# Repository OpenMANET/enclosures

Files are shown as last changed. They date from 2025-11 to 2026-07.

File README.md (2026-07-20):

# OpenMANET Enclosures

This repository collects 3D-printable and off-the-shelf enclosure designs that support OpenMANET nodes and accessories.

## Available Enclosures

| Name | Description |
|---|---|
| [Get Started Enclosure](GetStarted/README.md) | Simple Snap-fit Raspberry Pi 4 + HaLow enclosure with multiple UPS/no-UPS variants and ABS/ASA print guidance. |
| [OpenNot5](OpenNot5/README.md) | Aluminum or 3D printed field chassis that integrates a Pi 4B, Waveshare 3S UPS, and waterproof bulkhead connectors. MakerWorld listing: https://makerworld.com/en/models/2128181-openmanet-radio-case |
| [OpenChubNET](OpenChubNET/README.md) | 3D printed, Pi4B, Waveshare UPS D, CAZN connectors. Option for DIY top lids |
| [Hammond Enclosure](Hammond/README.md) | OpenMANET enclosure for a Pi 4B using a Hammond 1457K1201BK case plus printed cap/carrier tray; optional inline connector simplifies switch-to-PiSugar wiring for easier rework. |
| [PRC-148 / PRC-152 Battery](PRC-148-152-Battery/README.md) | Early community design for a 3S2P 18650 twist-lock radio battery and matching radio-side mount. |
| [Sunkworks VLM-PT1 Enclosure](<Sunkworks VLM PT1 Enclosure/README.md>) | Compact two-piece enclosure for the OpenVLM VLM-KW USB voice/PTT interface, with print files, hardware requirements, and assembly notes. |

## Other Prints

| Name | Description |
|---|---|
| [GIZOisNT](GIZOisNT_Antenna/README.md) | Tactical Gooseneck Antenna |

## Photo Gallery

**Get Started**

Get Started no-UPS build

**OpenNot5**

OpenNot5 field build

**OpenChubNET**

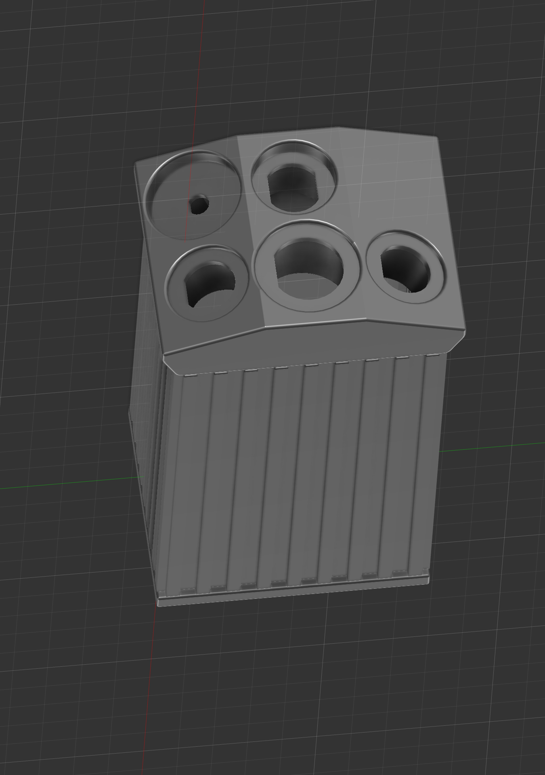
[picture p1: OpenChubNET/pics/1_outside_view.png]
OpenChubNET render


**Hammond**

Hammond enclosure front angle

Hammond enclosure rear angle

Hammond enclosure open with PiSugar 3 Plus

**Sunkworks VLM-PT1**

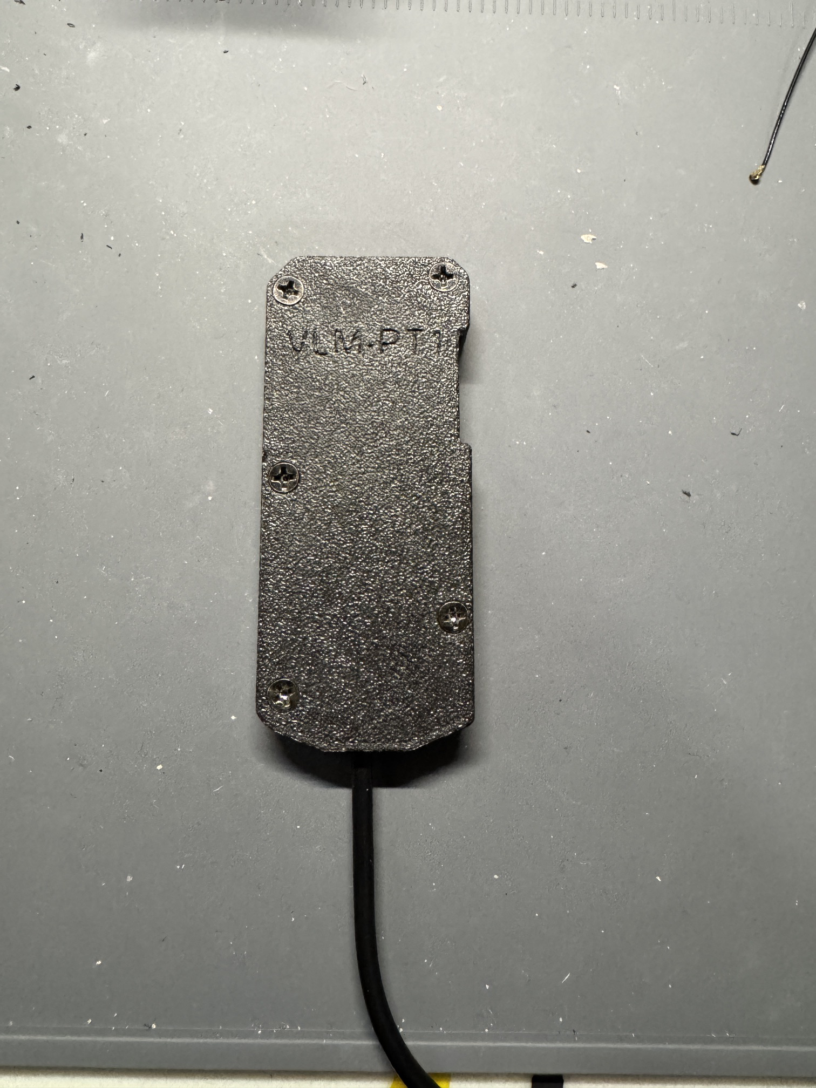
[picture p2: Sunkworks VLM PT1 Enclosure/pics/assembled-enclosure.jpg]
Assembled Sunkworks VLM-PT1 enclosure


**GIZOisNT**

GIZOisNT

## Contributing

1. Create a directory named after your enclosure.
2. Add a `README.md` describing the use case, assembly steps, and parts list (note optional vs required parts).
3. Include any supporting assets (STL files, wiring diagrams, photos) inside the same directory.

PRs that follow the structure above make it easier for others to build repeatable OpenMANET hardware.

## License

All content in this repository is provided under the [Creative Commons Attribution-NonCommercial 4.0 International](LICENSE) license. Commercial use requires explicit permission from the creator.

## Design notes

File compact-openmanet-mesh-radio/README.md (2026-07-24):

# Compact OpenMANET Mesh Radio Build

## Overview

This project is a compact radio-style mesh build designed around a 3D printed enclosure and internally mounted electronics. The enclosure is intended to keep the build clean, compact and practical, with externally mounted antennas and room for the required power and radio components.

Several versions and layout options are included in the full project repository. These include different enclosure versions, component layouts, antenna mounting options and internal build approaches.

Full repository:
https://github.com/ties1887/Mesh-radio-Halow-LoRa

## Preview pictures

<p align="center">
  
  
</p>

<p align="center">
  
  
</p>

<p align="center">
  db9d3973-dfbc-4dac-b72b-2cc7cdb6f751
  
</p>

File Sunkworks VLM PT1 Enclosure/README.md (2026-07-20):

# Sunkworks VLM-PT1 Enclosure

Compact two-piece enclosure for the OpenVLM VLM-KW USB voice/PTT interface.

Assembled VLM-PT1 enclosure

## Overview

- Fits the [Builds By Shane VLM-KW board](https://www.buildsbyshane.com/shop/p/product-3-szb2y-gzh2r-tzhkx-xahl8).
- Uses five heat-set inserts and five flat-head screws.
- Routes the USB and Kenwood-style PTT cables through opposite ends of the case.
- The included STL contains both enclosure halves.

A ready-made [Sunkworks VLM-PT1 enclosure kit](https://sunkworkstec.com/products/sw-vlm-pt1)
is printed in PPA-CF and includes mounting hardware and one selected USB cable.
The VLM board and PTT are sold separately.

## Photos

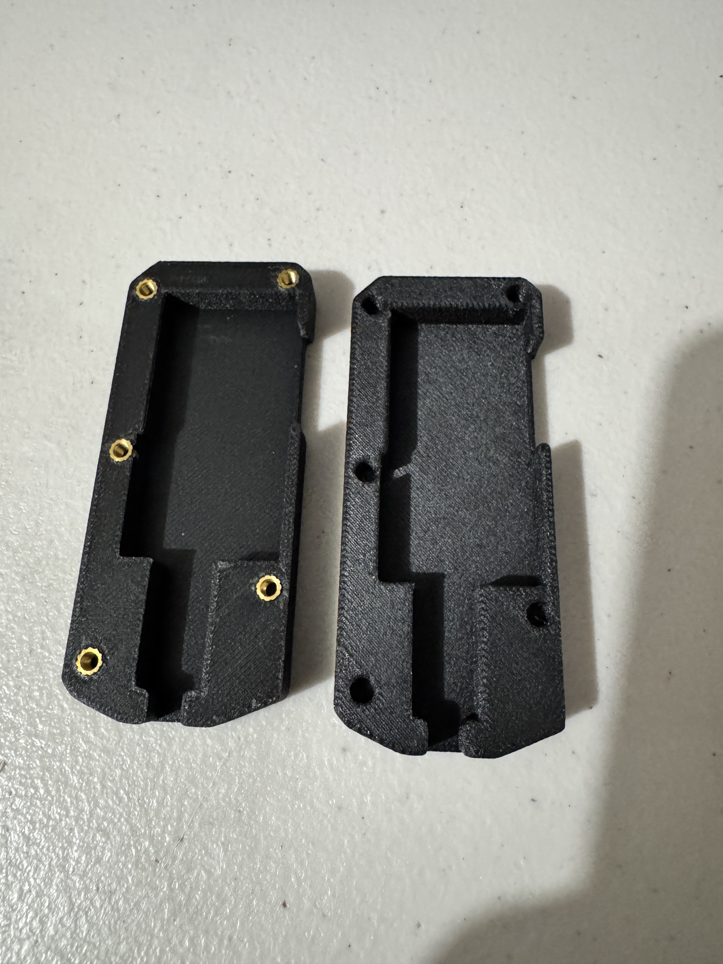
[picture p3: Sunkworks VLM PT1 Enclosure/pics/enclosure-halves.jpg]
Inside faces of the two printed VLM-PT1 enclosure halves


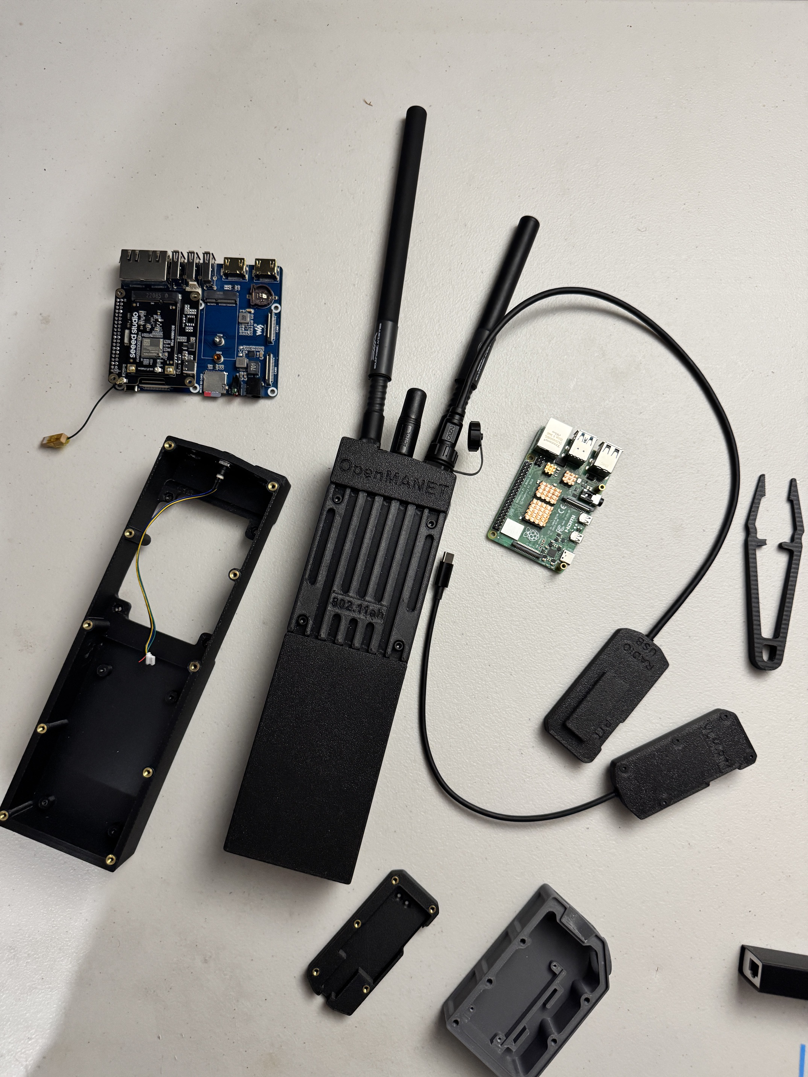
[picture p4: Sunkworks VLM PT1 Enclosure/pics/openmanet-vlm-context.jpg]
VLM-PT1 enclosure shown with OpenMANET hardware


## Bill of Materials

| Qty | Item | Notes |
|-----|---|---|
| 1 | VLM-KW board | Purchased separately |
| 1 | Printed VLM-PT1 enclosure | Both halves are in the included STL |
| 5 | M3 x 3 mm heat-set inserts | Install in the enclosure bosses |
| 5 | M3 x 6 mm flat-head Phillips screws | Join the enclosure halves |
| 1 | USB host cable | Match the connector to the host device |
| 1 | Compatible Kenwood 2-pin PTT | Purchased separately |

## Printing

1. Import [`stl/vlm-pt1-enclosure.stl`](stl/vlm-pt1-enclosure.stl).
2. Split the model into its two shell components.
3. Move the shells apart and orient each one separately for printing.
4. Confirm that the heat-insert bosses print cleanly before assembly.

## Assembly

1. Print and clean both enclosure halves.
2. Install the five M3 x 3 mm heat-set inserts, keeping them square and flush.
3. Dry-fit the VLM-KW board and route the USB and PTT cables through the case
   openings without pinching them.
4. Join the shells with the five M3 x 6 mm screws and tighten only until the seam
   closes.
5. Test the VLM before field use.

## Source Files

- [`stl/vlm-pt1-enclosure.stl`](stl/vlm-pt1-enclosure.stl) — both enclosure halves
- [`hardware/parts.txt`](hardware/parts.txt) — original fastener and cable notes
- [`pics/`](pics) — assembly and context photos

## Related Links

- [Sunkworks VLM-PT1 enclosure kit](https://sunkworkstec.com/products/sw-vlm-pt1)
- [OpenMANET/OpenVLM repository](https://github.com/OpenMANET/OpenVLM)
- [Builds By Shane VLM-KW board](https://www.buildsbyshane.com/shop/p/product-3-szb2y-gzh2r-tzhkx-xahl8)

## License

Repository content is covered by the root
[CC BY-NC 4.0 license](../LICENSE). The OpenVLM board and software repositories
carry their own licenses; review those projects before redistributing their
files.

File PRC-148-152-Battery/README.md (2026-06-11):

# PRC-148 / PRC-152 Battery

DIY rechargeable battery enclosure and radio-side mounting interface for
PRC-148 / PRC-152-style OpenMANET radios. The battery uses six 18650 cells in a
3S2P configuration and copies the nominal voltage and twist-lock interface of a
PRC-148 battery.

This is an early community design by Mark. The recovered source files and known
build details are collected here so the design can be tested, documented, and
improved.

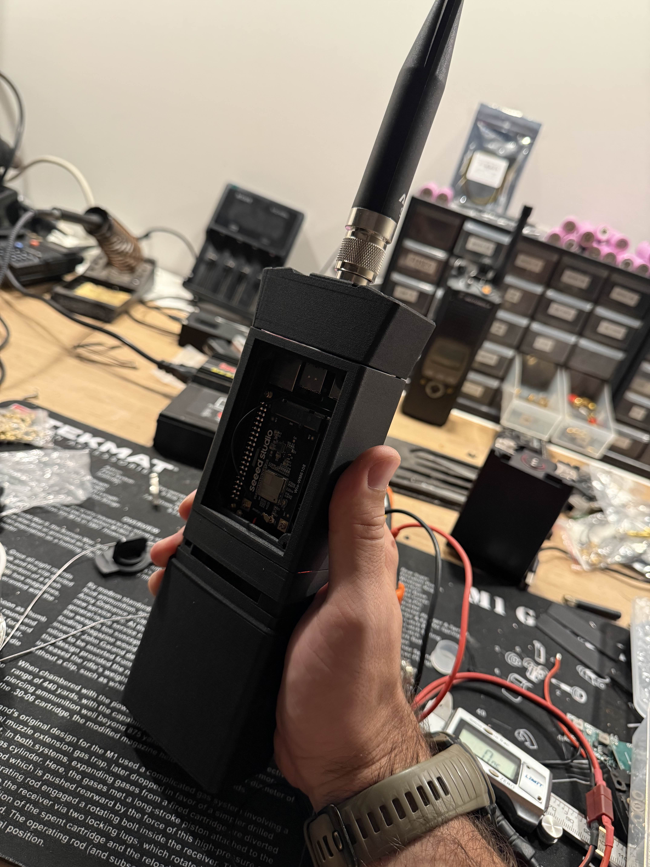
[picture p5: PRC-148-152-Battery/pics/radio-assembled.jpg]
Assembled radio and battery


> [!CAUTION]
> Building lithium-ion packs can cause fire, serious injury, or property damage.
> Use matched, genuine cells; a suitable 3S BMS; insulated weldable battery
> tabs; a current-limited spot welder; and a charger specifically intended for a
> 3S lithium-ion pack. Verify polarity, isolation, and pack voltage before
> connecting the battery to a radio.

## Status

The original prototype has been built and operated, but this is not yet a
complete, independently verified build guide. See [Open Questions](#open-questions)
before ordering parts or assembling a pack.

The interface is intended to accept genuine-style PRC-148 batteries as well.
Mark reported that an original battery physically fitted, but genuine-battery
electrical compatibility has not been independently verified.

The optional interface PCBs are also prototype hardware. In the June 2026
discussion, board revision `0.1` had been ordered but had not yet been reported
as electrically validated. Review the KiCad source and verify every net before
connecting a battery or radio.

## Electrical Specification

| Item | Specification |
|---|---|
| Cell type | 6 x 18650 lithium-ion cells |
| Cell configuration | 3S2P |
| Nominal pack voltage | 10.8 V |
| Maximum pack voltage | 12.6 V |
| Prototype cell capacity | Approximately 3400-3500 mAh per cell |
| Approximate pack capacity | 6800-7000 mAh, depending on cells |
| Protection / balancing | 3S BMS |
| Charging | Standard 12.6 V 3S lithium-ion charger through the top connector |
| Positive contacts | Two outer circular contacts |
| Data contact | Middle circular contact; routed through the optional interface PCBs but unused by the basic battery |
| Ground contacts | Both stainless-steel twist-lock tabs, connected to protected BMS output negative |
| Positive contact rating | Mark reports 2-3 A at 12 V per pin; two positive pins are used in parallel |

The BMS balance connections must be connected at the 4.2 V and 8.4 V series
nodes. Each node joins the corresponding parallel cell pair. Do not treat these
as optional outputs.

Mark's prototype was charged using an inexpensive generic 12.6 V 3S
lithium-ion charger. A charging dock can use the same mechanical interface as
the radio-side mount. A commercial `SN-832-KIT Rev B` charging-adapter STEP file
was shared in Discord as a mechanical reference, but it is not included here
because its redistribution license is unknown.

The interface PCBs do not convert the pack voltage. The radio still requires a
separate regulator or power supply suitable for its electronics. An MP1584EN
module was used elsewhere in Mark's prototype, but Mark described it as
temporary and community discussion identified RF-emission concerns.

## Mechanical Interface

The two stainless-steel tabs are both structural twist-lock features and
electrical ground contacts. Their angled surfaces tighten the battery against
the radio as the battery rotates into place. They must be conductive and cannot
be replaced with plastic prints.

Mark's prototype used SLM-printed 316L stainless-steel tabs. He reported a cost
of about USD $10 per pair. His PCBWay reference settings for the older
`Falcon Battery Tab v8` were:

| Item | Setting |
|---|---|
| Dimensions | 40.44 x 39.60 x 3.00 mm |
| Material | Stainless steel 316L |
| Process | SLM |
| Threads / inserts | None |

Mark subsequently modified the tab to fit countersunk pieces, so do not treat
the `v8` dimensions as the final production model. Sheet metal may also work if
it can be formed accurately, but that approach has not been documented or
verified here.

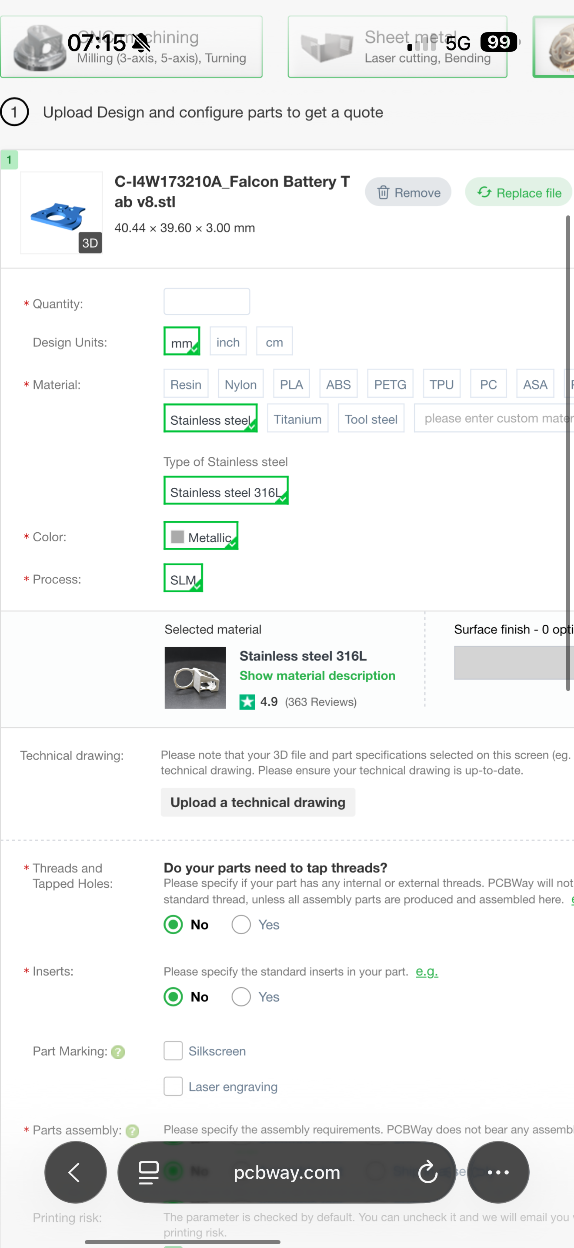
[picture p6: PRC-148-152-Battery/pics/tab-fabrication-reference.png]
PCBWay settings for the older Falcon Battery Tab v8


The center contact arrangement is:

| Side | Contact |
|---|---|
| Radio | 6 mm spring-loaded pogo pins |
| Battery | 2.0 x 7.0 mm flat-top pins, 1.5 mm body, no spring |

The pins are pushed in from the top with a tight friction fit. The prototype's
printed holes required minor drilling. Solder quickly to avoid heat damage;
wire-wrapping the pin before soldering is recommended.

An O-ring seals the circular contact insert. Mark specified `13.9 x 1.8 mm`.

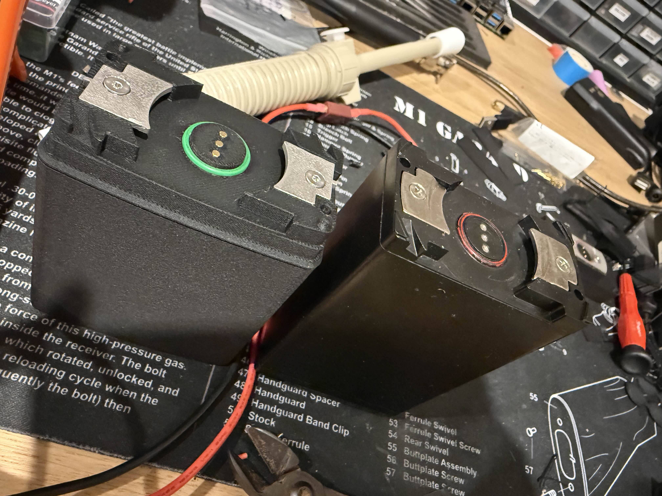
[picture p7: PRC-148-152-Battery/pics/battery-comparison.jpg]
Battery and commercial reference battery


## Related Electronics

The companion [mattronix/battery-board](https://github.com/mattronix/battery-board)
project replaces point-to-point wiring at the mechanical interface with two
PCBs.

### Battery-Side PCB

The battery board connects the BMS/output harness to the contacts and adds one
resettable fuse before the two parallel positive contacts.

| JST XH 3-pin | Signal | Destination |
|---|---|---|
| Pin 1 | `GND` | Both conductive twist-lock tabs |
| Pin 2 | `DATA` | Middle flat contact |
| Pin 3 | Raw `VBAT+` | Resettable fuse, then both outer positive contacts |

Connect the BMS protected output positive and negative to this harness. The
board's fuse protects the positive contacts, but it does not replace the 3S BMS.

### Radio-Side PCB

The radio board combines the two positive pogo pins, passes them through an
always-on P-channel MOSFET reverse-polarity stage, then through a 5 mOhm shunt.
An INA226 measures bus voltage and current across that shunt. The board does not
regulate the battery voltage.

| JST XH 6-pin | Signal | Purpose |
|---|---|---|
| Pin 1 | `GND` | Ground / both conductive twist-lock tabs |
| Pin 2 | `DATA` | Direct pass-through from the middle battery contact |
| Pin 3 | `SDA` | INA226 I2C data |
| Pin 4 | `SCL` | INA226 I2C clock |
| Pin 5 | `3V3` | Host-supplied INA226 power |
| Pin 6 | `VBAT+` | Monitored/protected battery output |

The middle `DATA` contact is independent of the INA226. INA226 telemetry uses
the separate `SDA` and `SCL` harness pins and requires host software. The
current design grounds both INA226 address pins and leaves its alert output
unconnected.

The PCB project is licensed separately under CERN-OHL-W-2.0.

> [!WARNING]
> The board repository's prose documentation has described the INA226 as
> reporting over the battery `DATA` line. The current KiCad design does not do
> that: `DATA` is a separate pass-through, while the INA226 uses `SDA` and `SCL`
> on the radio-side six-pin harness.

## Bill of Materials

| Qty | Part | Known specification / source | Notes |
|-----|---|---|---|
| 6 | 18650 cells | Matched 3.6 V nominal cells | Prototype used 3400-3500 mAh cells |
| 1 | 3S BMS | [Original AliExpress listing](https://www.aliexpress.com/item/1005009778488275.html) | Confirm current rating and wiring before assembly |
| 3 | Radio-side spring contacts | [6 mm pogo pin listing](https://www.aliexpress.com/item/1005006095992803.html) | Used on radio side |
| 3 | Battery-side flat contacts | [Original listing](https://www.aliexpress.com/item/32862727404.html) | 2.0 x 7.0 mm, 1.5 mm body, no spring |
| 1 | O-ring | 13.9 x 1.8 mm | Circular contact insert seal |
| 2 | Conductive twist-lock tabs | SLM-printed 316L stainless steel | Both tabs are ground contacts |
| 1 set | Cell interconnects | Weldable battery tabs sized for expected current | Mark welded tabs to the cells, then soldered cables to the tabs; confirm tab material |
| 1 set | Wire and insulation | Sized for expected current and pack voltage | Include fish paper / equivalent cell insulation |
| 1 | 3S lithium-ion charger | 12.6 V CC/CV charger | Connects through top interface |
| 1 set | Fasteners / inserts | To be confirmed | See Open Questions |
| Optional | Battery and radio interface PCBs | [mattronix/battery-board](https://github.com/mattronix/battery-board) | Adds contact breakout, battery-side resettable fuse, radio-side reverse-polarity protection, and INA226 monitoring |

## Source Files

### Battery

The [`cad/battery`](cad/battery) directory contains:

- `Battery Case` Fusion 360 and STL files
- `BatteryTop v1` Fusion 360 and STL files
- `18650 Holder Top` Fusion 360 and STL files
- `18650 Holder Bottom` Fusion 360 and STL files
- `Falcon Battery Tab v13` conductive twist-lock tab Fusion 360 and STL files
- `PRC Cell.3mf` prepared multi-part print project

### Radio

The [`cad/radio`](cad/radio) directory contains the matching
`148_152_Radio_Bottom` Fusion 360 and STL files.

`Falcon Battery Tab v13` is the current available conductive-tab design and
includes both an editable Fusion 360 source and an STL.

## Assembly Outline

1. Print and dry-fit all battery parts and the radio-bottom counterpart.
2. Obtain or manufacture the conductive stainless-steel twist-lock tabs.
3. Install the flat battery-side contacts and O-ring in the battery top.
4. Build a matched 3S2P cell pack using a spot welder and suitable insulation.
   Mark spot-welded tabs to the cells and then soldered cables to the tabs. Do
   not solder directly to bare cells.
5. Wire both parallel groups to the BMS, including the 4.2 V and 8.4 V balance
   nodes.
6. If wiring without the battery-side PCB, connect both outer circular contacts
   to BMS protected output positive and leave the middle data contact unused.
   If using the PCB, connect BMS protected output positive to JST pin 3; the
   board's resettable fuse feeds both positive contacts.
7. Connect both conductive twist-lock tabs to BMS protected output negative,
   not directly to raw cell negative. With the battery-side PCB, use JST pin 1.
8. Leave battery-board JST pin 2 / the middle `DATA` contact disconnected unless
   implementing a compatible battery-side data system. It is not used for
   INA226 monitoring.
9. Verify there are no shorts between positive, data, ground tabs, or exposed
   fasteners.
10. Confirm correct polarity and pack voltage with a multimeter before mating
    the battery to the radio.
11. Perform initial charge and load testing in a fire-resistant location.

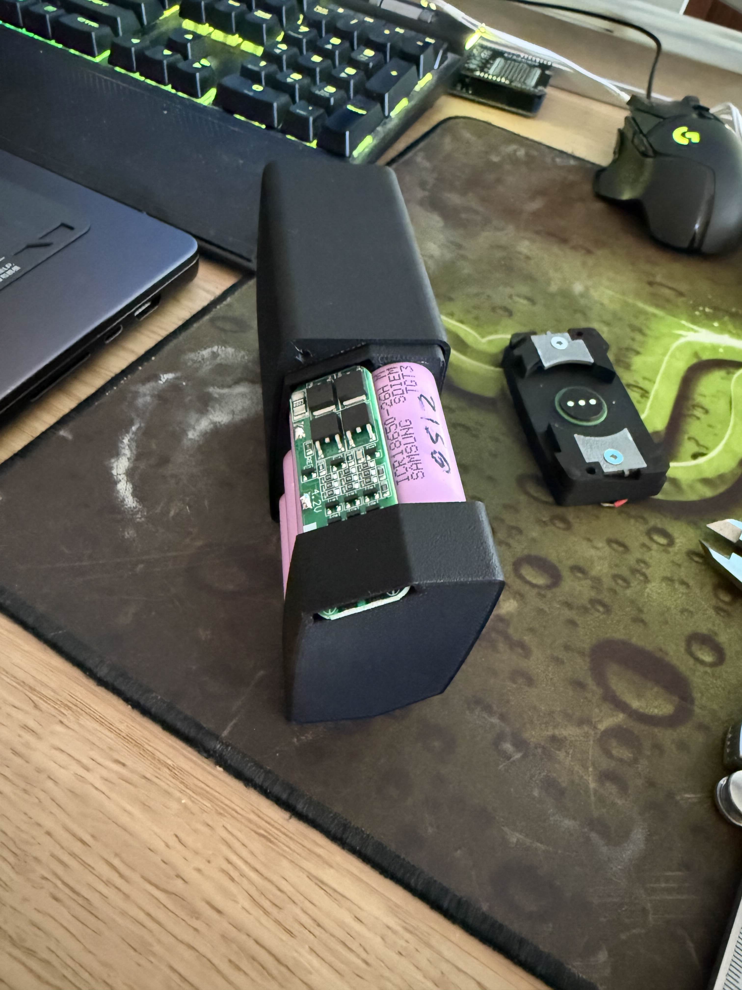
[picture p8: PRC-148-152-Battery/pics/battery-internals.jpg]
Battery internals and BMS


## Open Questions

The following details need confirmation before this can be considered a
repeatable build guide:

- Confirmed v13 tab fabrication settings and fit. The recovered
  fabrication-reference screenshot is for the older `v8` tab.
- Exact screws, heat-set inserts, and fastener lengths.
- Verified BMS model, current rating, protection thresholds, and complete wiring
  diagram.
- Recommended cell model, continuous current rating, nickel-strip dimensions,
  wire gauge, and battery-board resettable-fuse rating.
- Confirmed polarity diagram viewed from both the battery and radio sides.
- Recommended print material, orientation, layer height, walls, and infill.
- Environmental sealing and water-resistance test results.
- Mechanical fit across different PRC-148 / PRC-152 reproduction bodies.
- Final charging-dock design and safe charging procedure.
- Radio-side harness integration, INA226 software support, and validation of the
  MOSFET/shunt path at the intended continuous and peak currents.

## License

Licensing for Mark's original CAD and photos needs confirmation from Mark before
redistribution. This repository otherwise uses its root
[CC BY-NC 4.0 license](../LICENSE). Do not assume GPL applies to these files
until the creator explicitly selects and grants that license.

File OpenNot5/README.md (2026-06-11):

# Open Not 5 Node Enclosure

## Overview

This enclosure is designed for OpenMANET field nodes and integrates a Raspberry
Pi 4B with an internal battery-backed UPS. The aluminum chassis doubles as a
passive heatsink and keeps all I/O accessible through waterproof bulkhead ports.
The enclosure can also be 3D printed, but thermal performance may be reduced.

Example enclosure build

Printable files and additional build notes are available on
[MakerWorld](https://makerworld.com/en/models/2128181-openmanet-radio-case).

## Assembly

1. Print the enclosure files or prepare the aluminum chassis.
2. Install the required heat-set inserts.
3. Mount the Raspberry Pi 4B, WM1302 Pi HAT, WM6180 module, and UPS.
4. Install the 18650 cells and complete the power wiring.
5. Install the waterproof Ethernet port, antenna pigtails, and antennas.
6. Verify operation and seal the enclosure.

## Bill of Materials

Based on OutlawLabs document `BOM-OMNT-001`, revision `1.0`, dated
April 28, 2026.

### Core Electronics

| Qty | Component | Specification / Source |
|-----|---|---|
| 1 | Raspberry Pi 4 Model B | 1 GB RAM minimum; ARM Cortex-A72; USB 3.0; Gigabit Ethernet |
| 1 | SD card | Class 10 / A1 recommended; 16 GB minimum |
| 1 | Wio WM6180 Wi-Fi HaLow module | Mini PCIe; 802.11ah; sub-1 GHz |
| 1 | WM1302 Pi HAT | LoRaWAN gateway HAT for Raspberry Pi; SPI interface |
| 1 | CAZN RJ45 Ethernet port | [Panel-mount RJ45 connector](https://s.click.aliexpress.com/e/_c3y8oRGt) |

### RF and Antennas

Choose either antenna option A or B for the 868 / 915 MHz radio.

| Qty | Component | Specification / Source |
|-----|---|---|
| 1 | Option A: Mesh Ant | [868 / 915 MHz; 2 dBi; BNC; ZBM2 Industries](https://zbm2industries.com/products/mesh-ant) |
| 1 | Option B: Mesh Goose Neck antenna | [868 / 915 MHz; 2 dBi; BNC; ZBM2 Industries](https://zbm2industries.com/products/mesh-goose-neck?_pos=1&_sid=85e2e1a47&_ss=r) |
| 1 | SMA-F to BNC-M adapter | [Required for antenna option A or B](https://zbm2industries.com/products/sma-f-to-bnc-m) |
| 1 | GPS antenna: Mesh Stubby | [GPS / GNSS compact stub; ZBM2 Industries](https://zbm2industries.com/products/mesh-stubby?variant=45259893833880) |
| 1 | U.FL to SMA-K pigtail cable | 1.13 mm coax; 120 mm length; U.FL / IPEX connector |

### Power System

| Qty | Component | Specification / Source |
|-----|---|---|
| 1 | Waveshare 3S UPS HAT | 3-cell 18650 UPS; USB-C; I2C fuel gauge; 5 V output |
| 1 | USB-C FPC charging cable | [USB-C male soft-flat charging cable, available in 2-pin / 3-pin resistor variants](https://a.aliexpress.com/_mPbpBKL); select the correct variant for the build |
| 3 | 18650 rechargeable batteries | 3.7 V nominal; 2500 mAh minimum; protected cells recommended |

### Fasteners and Inserts

| Qty | Component | Specification |
|-----|---|---|
| 14 | M3 screws | Stainless steel; length TBD per assembly drawing |
| 4 | M3 bolts | Stainless-steel hex bolts |
| 10 | M3 heat-set threaded inserts | Brass; M3 x 5 mm OD x 5 mm L; press-fit for 3D print |
| 8 | M2.5 screws | Stainless steel; length TBD per assembly drawing |
| 8 | M2.5 heat-set threaded inserts | Brass; M2.5 x 3.5 mm OD x 5 mm L; press-fit for 3D print |

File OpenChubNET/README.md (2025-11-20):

# OpenChubNET Enclosure

## Overview
This enclosure is designed for OpenMANET field nodes and integrates a Pi 4B with an internal battery-backed UPS.

## Philosophy

- A large enough case to fit the bulkiest SBC + UPS + Hat configuration. Room on one side of the case to pass through thin USB to power and USB eth.
- A mounting board that the SBC sits on which slides into the case, it has holes to pass through cables. The board translates different SBC + UPS + Hat configurations to fit the case
- Multiple top lids with various antenna configurations depending on antenna types, number of antennas, Power over USB, EUD eth over USB, buttons etc.

## Order of build
1. Print files 
2. Mount the Pi4B and Waveshare D UPS to the printed mounting plate
3. Add the Li-ion battery and wiring
5. Assemble connectors to lid
6. Connect antennas
7. Connect USB cables to hardware
8. Install and test OpenMANET as per [instructions](https://openmanet.github.io/docs/initial-setup.html)

## Parts List

### Baseline
- 1 x Raspberry Pi 4B
- 1 x [Waveshare UPS HAT D](https://www.waveshare.com/ups-hat-d.htm)
- 2 x 21700 3.7V rechargeable lion batteries

### Connectors
- 2 x [CAZN USB-C waterproof port](https://www.aliexpress.us/item/3256806032665821.html)
- 1 x [CAZN RJ45 waterproof](https://www.aliexpress.com/item/1005006207254042.html)
- (alternative) 1 x [CAZN RJ45 waterproof 180 degrees](https://www.aliexpress.com/item/1005006207174223.html)

### Antenna cables
- 1 x [NType to UFL RG178 20cm](https://www.aliexpress.com/item/1005008877279360.html)
- 1 x [SMA to UFL 20cm](https://www.aliexpress.com/item/1005005697399884.html)

### Antennas
- 1 x [Gizont 915MHz gooseneck NType](https://www.aliexpress.com/item/1005006433957349.html)
- 1 x [Gizont GPS Stubby](https://www.aliexpress.com/item/1005006022171372.html)

## Options

### Antenna cables

I went with NType and thicker RG178 cables, but TNC or SMA options are available at resellers.

### Antennas

Gooseneck, whips, spring flexible. Check out Gizont store on Aliexpress

### Aliexpress resellers

- [Gizont Factory Store](https://www.aliexpress.com/store/1103206200)
- [CAZN Factory Store](https://www.aliexpress.com/store/1103206200)

## Print instructions

### Case

Print standing up. No supports needed

- [Case](stl/openMANET_enclosure_rpi4_ups_battery_rj45.stl)

### Mounting plate

Print laying down. No supports needed

- [Board](stl/openMANET_mounting_plate.stl)

### Top

Print laying down or at 45 degree for fewer supports. Supports needed.

- [Top](stl/openMANET_top_usbc_rj45_ntype_sma.stl)

## DIY top lids

There is a [top lid stencil](stl/openMANET_stencil_top.stl) which can be use to punch out holes to your liking

Additionally there are punches for 

- [CAZN RJ45](stl/openMANET_stencil_cazn_rj45.stl)
- [CAZN USB](stl/openMANET_stencil_cazn_usb.stl)
- [NType](stl/openMANET_stencil_ntype.stl)
- [SMA](stl/openMANET_stencil_sma.stl)

In Fusion 360 add the stencils to the top, combine, cut. 

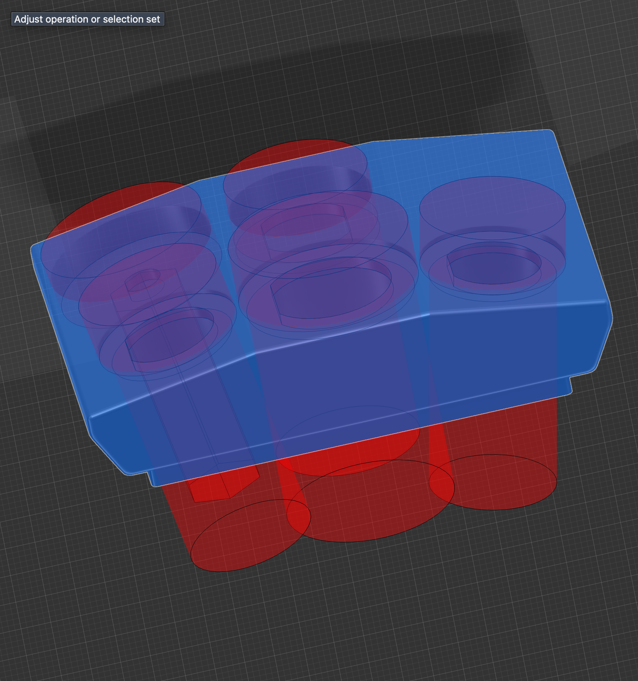
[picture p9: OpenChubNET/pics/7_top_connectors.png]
Result


## Reference images

Outside view
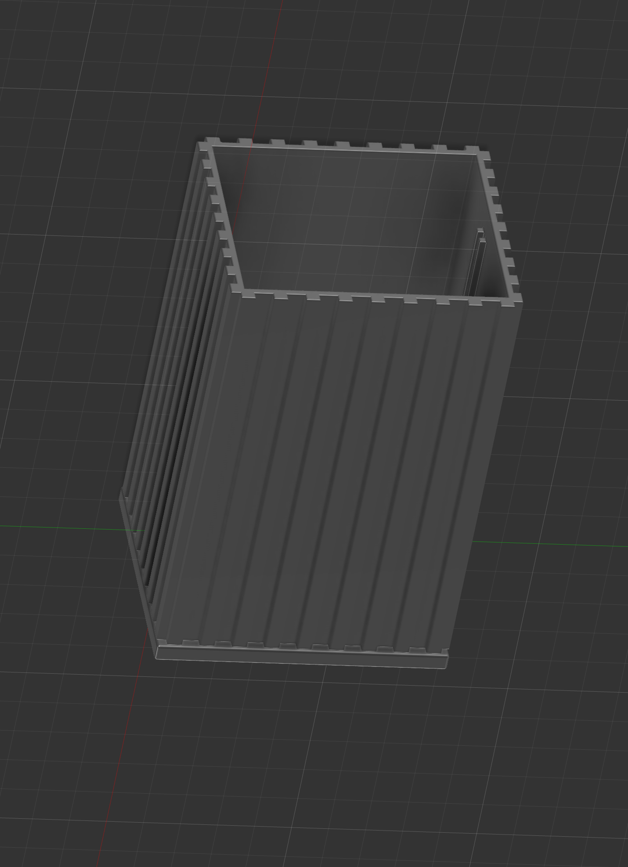
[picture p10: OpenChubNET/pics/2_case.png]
Case

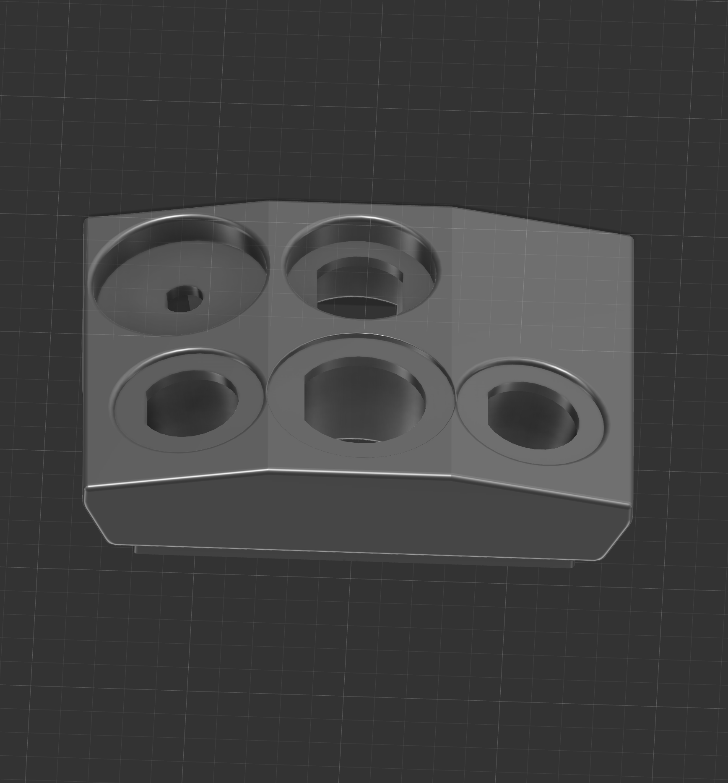
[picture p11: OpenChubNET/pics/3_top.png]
Top

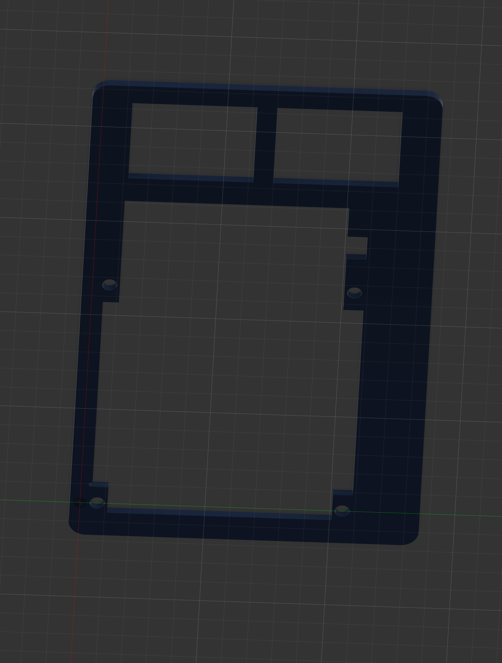
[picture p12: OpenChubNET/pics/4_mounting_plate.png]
Mounting plate

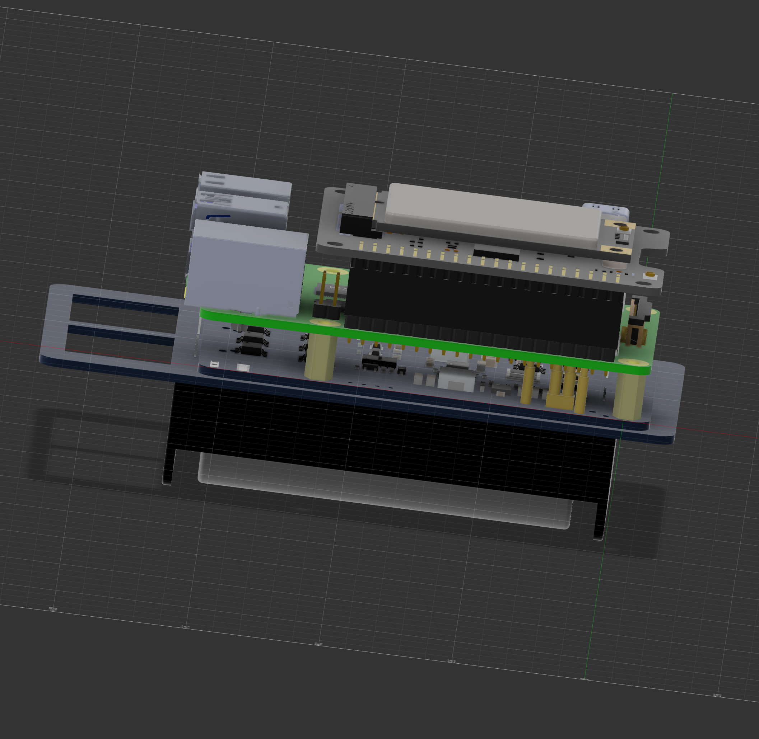
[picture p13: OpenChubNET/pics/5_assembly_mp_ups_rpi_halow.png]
Assembly 1

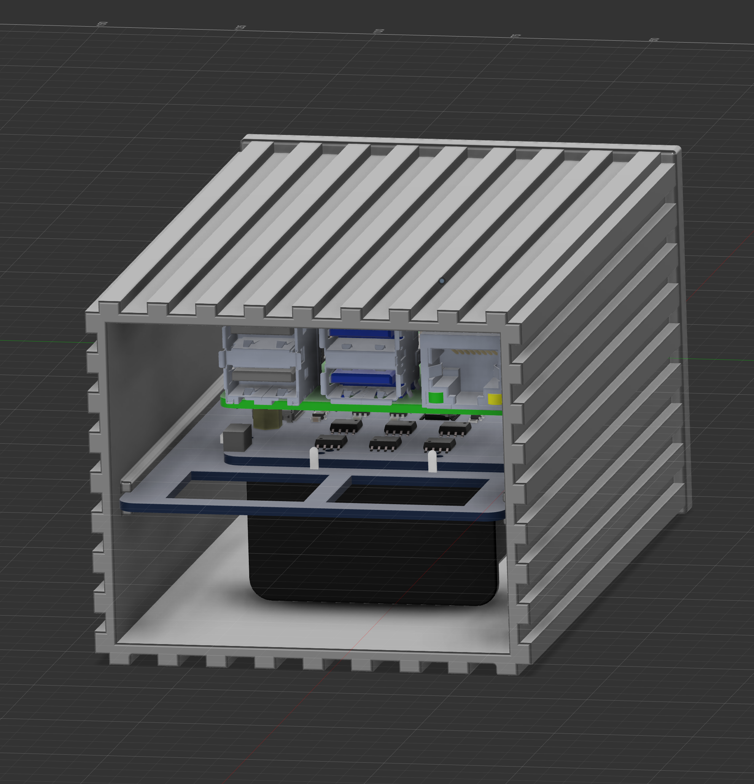
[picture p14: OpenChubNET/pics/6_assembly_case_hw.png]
Assembly 2


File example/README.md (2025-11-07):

# Example Enclosure

This sample enclosure documents the expected level of detail for OpenMANET builds. Use it as a starting point when you document your own hardware, swapping in your enclosure-specific files, wiring notes, and mechanical considerations.

## Overview

- Houses a Raspberry Pi 4, HaLow radio, antennas, and optional power accessories.
- Demonstrates how to call out required vs optional parts so builders can adapt to their needs.
- Intended for field-friendly deployments where ruggedness and quick maintenance matter.

## Recommended Parts List

| Item | Optional |
|---|---|
| [Wio WM6180 Wi-Fi HaLow mini PCIe Module](https://www.seeedstudio.com/Wio-WM6180-Wi-Fi-HaLow-mini-PCIe-Module-p-6394.html) | No |
| [WM1302 Pi Hat](https://www.seeedstudio.com/WM1302-Pi-Hat-p-4897.html) | No |
| [External Antenna 868/915 MHz 2 dBi SMA Foldable](https://www.seeedstudio.com/External-Antenna-868-915MHZ-2dBi-SMA-L195mm-Foldable-p-5863.html) | No |
| [UF.L to SMA-K 1.13 mm Cable (120 mm)](https://www.seeedstudio.com/UF-L-SMA-K-1-13-120mm-p-5046.html) | No |
| [Raspberry Pi 4 Model B (1 GB or greater)](https://www.seeedstudio.com/Raspberry-Pi-4-Computer-Model-B-1GB-p-4078.html) | No |
| [21700 Rechargeable Batteries](https://www.amazon.com/dp/B0D3GX96H6?ref_=ppx_hzsearch_conn_dt_b_fed_asin_title_4) | Yes |
| [WaveShare UPS B (18650 version)](https://www.amazon.com/gp/product/B0D39VDMDP/ref=ox_sc_saved_title_1?smid=A3B0XDFTVR980O&psc=1) | Yes |
| [Panda PAU06 USB Wi-Fi Adapter](https://www.amazon.com/dp/B00762YNMG?ref_=ppx_hzsearch_conn_dt_b_fed_asin_title_1) | Yes |
| [USB GPS Receiver (u-blox based)](https://www.amazon.com/dp/B01MTU9KTF?ref_=ppx_hzsearch_conn_dt_b_fed_asin_title_1) | Yes |

## Assembly notes

1. Mount the Raspberry Pi and WM1302 Pi Hat inside your enclosure, ensuring sufficient clearance for the UF.L cables.
2. Route the UF.L to SMA pigtails through the panel and affix the external antennas to maintain RF performance.
3. If battery-backed, secure the UPS and cells with non-conductive spacers and verify airflow for passive cooling.
4. Document any STL/STEP files, panel cutouts, or wiring diagrams in this directory so others can reproduce the build.

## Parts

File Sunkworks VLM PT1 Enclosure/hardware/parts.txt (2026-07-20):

VLM-PT1 hardware notes

- 5 x M3 x 3 mm heat-set inserts
- 5 x M3 x 6 mm flat-head Phillips screws
- CAZN USB-C cable: https://www.aliexpress.us/item/3256806032242845.html
- Complete enclosure kits: https://sunkworkstec.com/products/sw-vlm-pt1

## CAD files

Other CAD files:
GetStarted/stl/open manet enclosure WAVESHARE UPS D main body.stl
Hardware/HalowLink2/HalowLink2 Mechanical Assembly.STEP
OpenNot5/obj_1_openMANET main body .stl
GetStarted/stl/open manet enclosure pisugar ups main body.stl
GetStarted/stl/open manet enclosure no ups main body.stl
GIZOisNT_Antenna/model files/adapter_tnc.stl
GIZOisNT_Antenna/printer files/GIZOisNT.3mf
Hammond/stl/OpenMANET halow enclosure top cap rev3.stl
OpenChubNET/stl/OpenChubnet_slim.3mf
OpenNot5/obj_3_openMANET front panel.stl
PRC-148-152-Battery/cad/battery/Falcon Battery Tab v13.stl
PRC-148-152-Battery/cad/radio/148_152_Radio_Bottom.stl
Sunkworks VLM PT1 Enclosure/stl/vlm-pt1-enclosure.stl
GetStarted/stl/open manet enclosure WAVESHARE UPS D hatch REV1.stl.stl
GIZOisNT_Antenna/model files/tube_150mm.stl
Hammond/stl/OpenMANET halow enclosure carrier tray rev3.stl
OpenChubNET/stl/openMANET_mounting_plate.stl
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

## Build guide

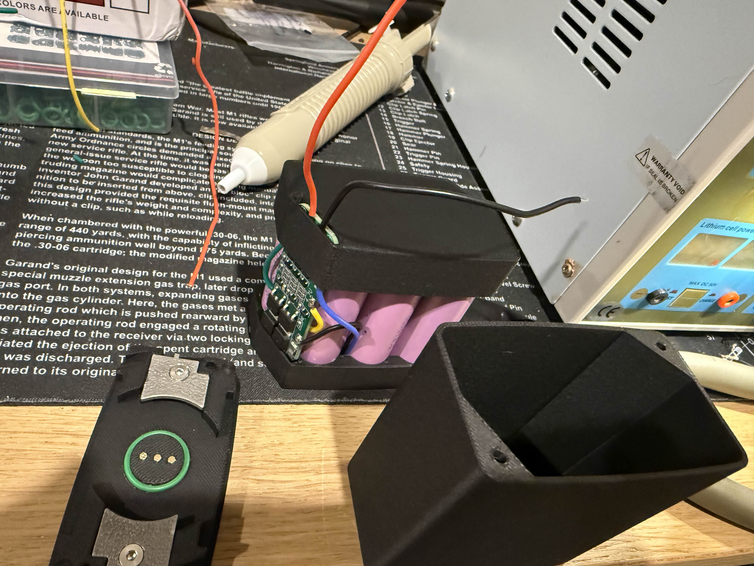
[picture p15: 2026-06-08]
PRC-148-152-Battery/pics/battery-assembly.jpg

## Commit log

2025-11-20 Initial commit.
    [openMANET_enclosure_rpi4_ups_battery_rj45.stl, openMANET_mounting_plate.stl, openMANET_top_usbc_rj45_ntype_sma.stl]
2025-11-21 Updated stl
    [openMANET_enclosure_rpi4_ups_battery_rj45.stl, openMANET_mounting_plate.stl, openMANET_top_usbc_rj45_ntype_sma.stl]
2026-03-28 Add Hardware folder, added HalowLink2 Folder, step file and readme (#15)
    * HalowLink2 Board
    Mechanical assembly of halowlink2 board. RJ45 connectors are not correct type, but correct loctions. heat sinks are separate parts fasteners are in correct orientation
    * Create HalowLink2
    * Rename HalowLink2 Mechanical Assembly.STEP to Hardware/HalowLink2 Mechanical Assembly.STEP
    * Rename HalowLink2 to HalowLink2 rm
    * Rename Hardware/HalowLink2 Mechanical Assembly.STEP to Hardware/HalowLink2/HalowLink2 Mechanical Assembly.STEP
    * Rename Hardware/HalowLink2 rm to Hardware/HalowLink2/HalowLink2 rm
    * Update and rename HalowLink2 rm to HalowLink2 ReadMe
    [HalowLink2 Mechanical Assembly.STEP]
2026-06-08 Add battery docs
    [148_152_Radio_Bottom.f3d, 148_152_Radio_Bottom.stl, 18650 Holder Bottom.f3d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]
2026-06-08 Add OpenNot5 case back
    [148_152_Radio_Bottom.f3d, 148_152_Radio_Bottom.stl, 18650 Holder Bottom.f3d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]
2026-06-11 Add Falcon battery tab v13
    [Falcon Battery Tab v13.f3d, Falcon Battery Tab v13.stl]
2026-06-11 Add OpenNot5 USB-C charging cable
2026-06-11 Remove Falcon battery tab v12
    [Falcon Battery Tab v12.stl]
2026-07-20 Add Sunkworks VLM-PT1 enclosure
    [vlm-pt1-enclosure.stl]
2026-10-17 Add rdt_manet_enclosure: 3D-printable MANET radio enclosure
2026-10-17 Add enclosure images to rdt_manet_enclosure
